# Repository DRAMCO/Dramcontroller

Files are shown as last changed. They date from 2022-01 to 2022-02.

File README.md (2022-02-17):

# Dramcontroller
HID controller board design for Engineering Experience 2.
The peripherals with corresponding pins are described below. 
A distinction is made between the on-board peripherals, I2C addresses and sensor slots

## On-board peripherals
| Peripherals | Corresponding GPIO Pin  |
|---|---|
| Buzzer | 2 |
| Vibrator 1 | 12 |
| Vibrator 2 | 5 |
| Debug LED | 13 |
| IO Expender INT | 11 |

## I2C addresses
Four IO expanders connected with the I2C bus control the 7 segment displays, led indicator array and GPIO 3 from every sensor slot. I2C sensors should use always other addresses to prevent collisions during operation.

| IO Expander | Corresponding I2C addres  |
|---|---|
| Sensor slot GPIO 3 | 0x38 |
| Segment display 2 | 0x39 |
| Segment display 1 | 0x3A |
| Led array | 0x3B |

## Sensor slots
### Sensor slot 1
| Peripheral | Pin | Comment |
|---|---|---|
| GPIO 1 | 6 | Digital |
| GPIO 2 | 14  | Digital - Analog |
| GPIO 3 | IO EXP pin 1 | Digital (0b00000001) |
| UART  |  | Serial |
| I2C  |  |  |

### Sensor slot 2
| Peripheral | Pin | Comment |
|---|---|---|
| GPIO 1 | 39 | Digital |
| GPIO 2 | 15  | Digital - Analog |
| GPIO 3 | IO EXP pin 2 | Digital (0b00000010) |
| UART  |  | Serial |
| I2C  |  |  |

### Sensor slot 3
| Peripheral | Pin | Comment |
|---|---|---|
| GPIO 1 | 8 | Digital |
| GPIO 2 | 16  | Digital - Analog |
| GPIO 3 | IO EXP pin 3 | Digital (0b00000100) |
| UART  |  | Serial |
| I2C  |  |  |

### Sensor slot 4
| Peripheral | Pin | Comment |
|---|---|---|
| GPIO 1 | 9 | Digital |
| GPIO 2 | 17  | Digital - Analog |
| GPIO 3 | IO EXP pin 4 | Digital (0b00001000) |
| UART  |  | Serial |
| I2C  |  |  |

### Sensor slot 5
| Peripheral | Pin | Comment |
|---|---|---|
| GPIO 1 | 10 | Digital |
| GPIO 2 | 18  | Digital - Analog |
| GPIO 3 | IO EXP pin 5 | Digital (0b00010000) |
| UART  |  | Serial1 |
| I2C  |  |  |

### Sensor slot 6
| Peripheral | Pin | Comment |
|---|---|---|
| GPIO 1 | 23 | Digital |
| GPIO 2 | 19  | Digital - Analog |
| GPIO 3 | IO EXP pin 6 | Digital (0b00100000) |
| UART  |  | Serial1 |
| I2C  |  |  |

### Sensor slot 7
| Peripheral | Pin | Comment |
|---|---|---|
| GPIO 1 | 24 | Digital |
| GPIO 2 | 4  | Digital - Analog |
| GPIO 3 | IO EXP pin 7 | Digital (0b01000000) |
| UART  |  | Serial1 |
| I2C  |  |  |

### Sensor slot 8
| Peripheral | Pin | Comment |
|---|---|---|
| GPIO 1 | 22 | Digital |
| GPIO 2 | 3  | Digital - Analog |
| GPIO 3 | IO EXP pin 8 | Digital (0b10000000) |
| UART  |  | Serial1 |
| I2C  |  |  |

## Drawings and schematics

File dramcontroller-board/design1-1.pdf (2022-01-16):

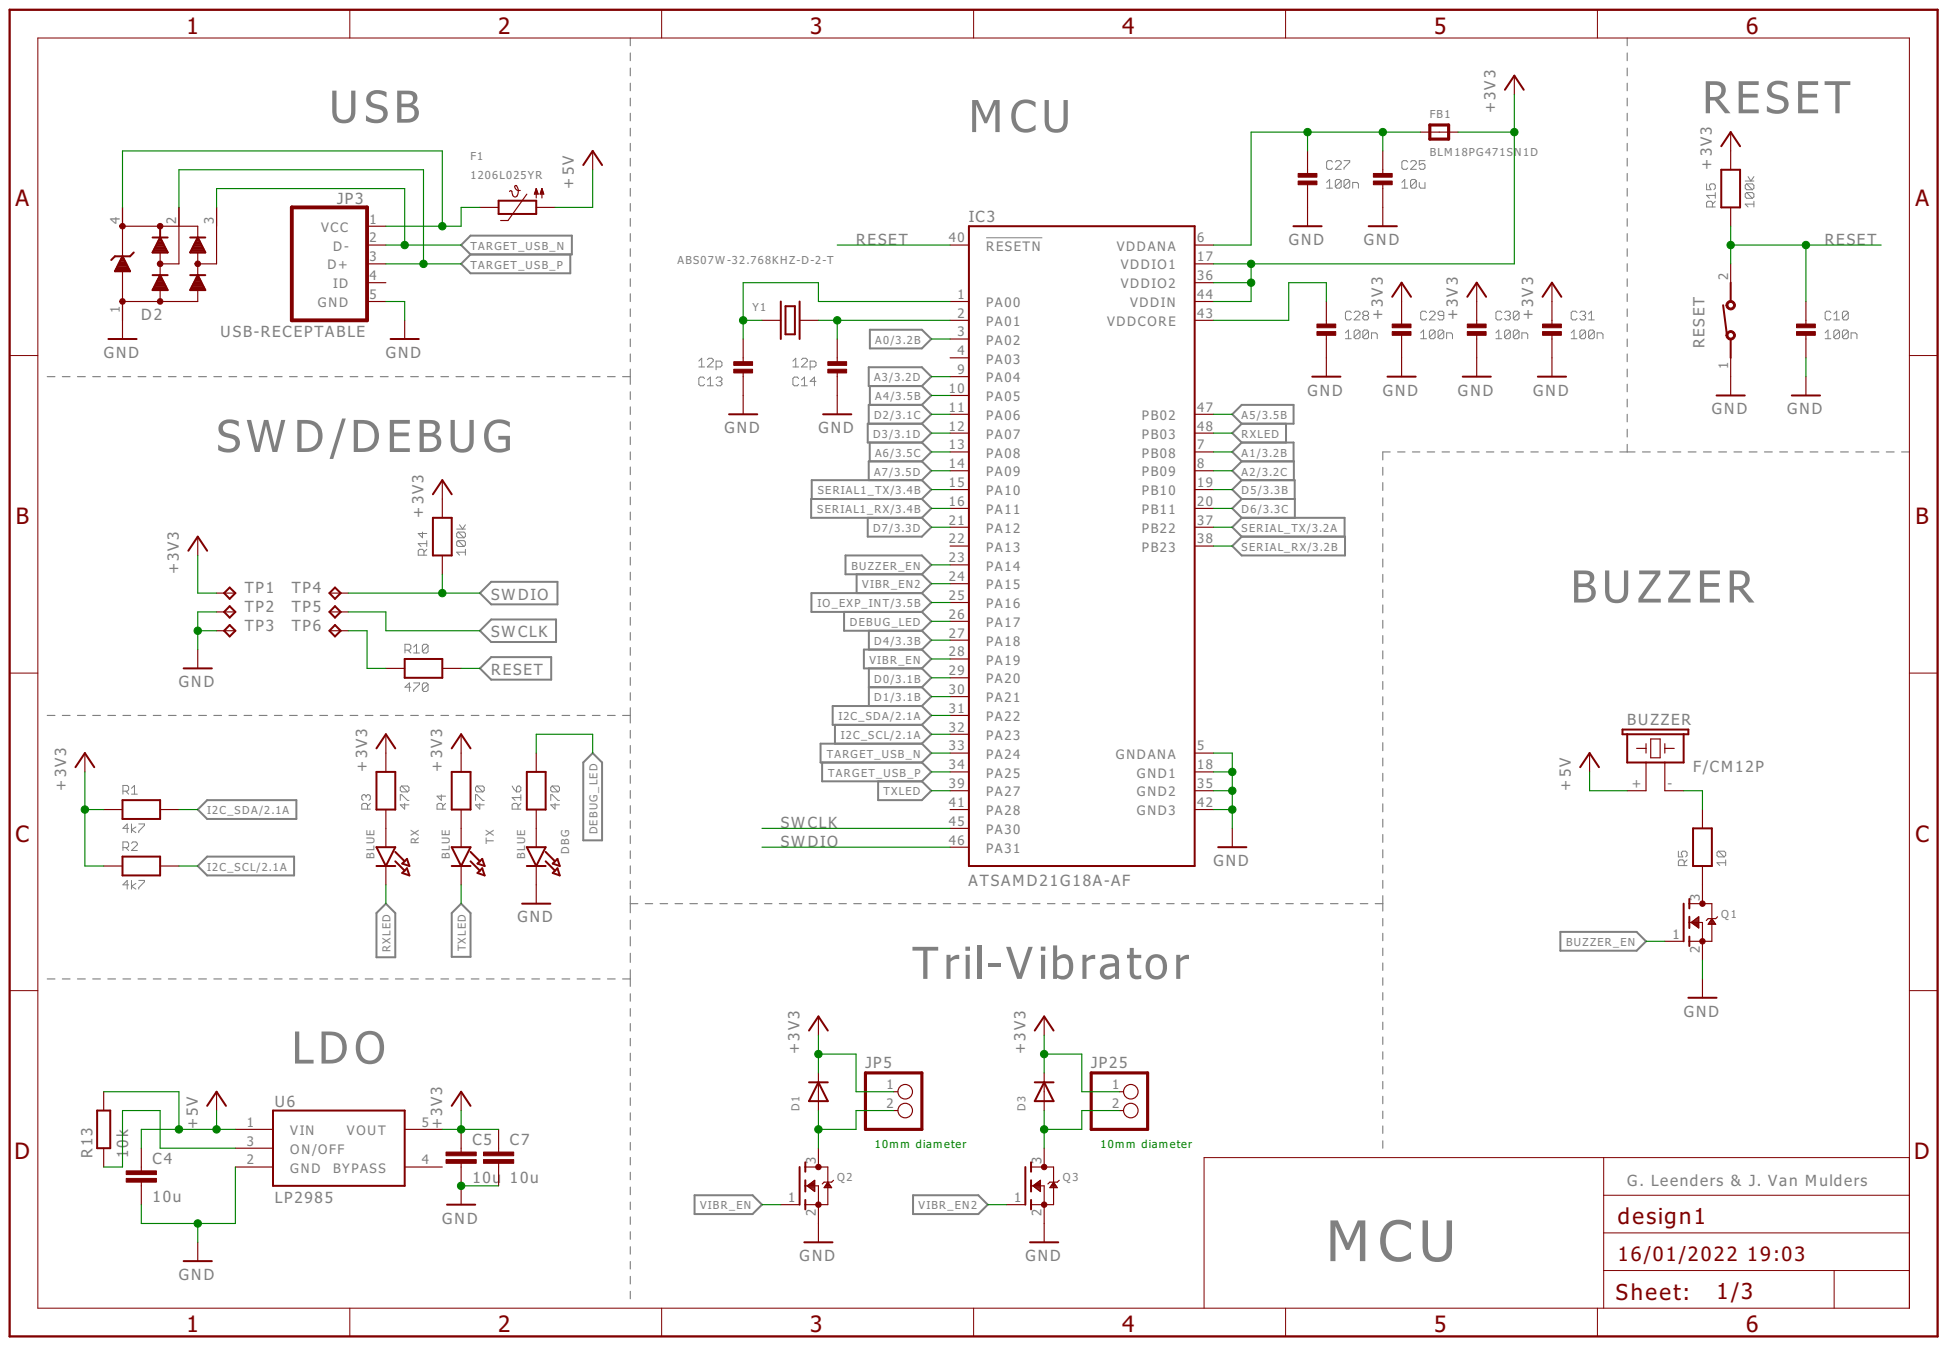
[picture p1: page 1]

G. Leenders & J. Van Mulders LDO

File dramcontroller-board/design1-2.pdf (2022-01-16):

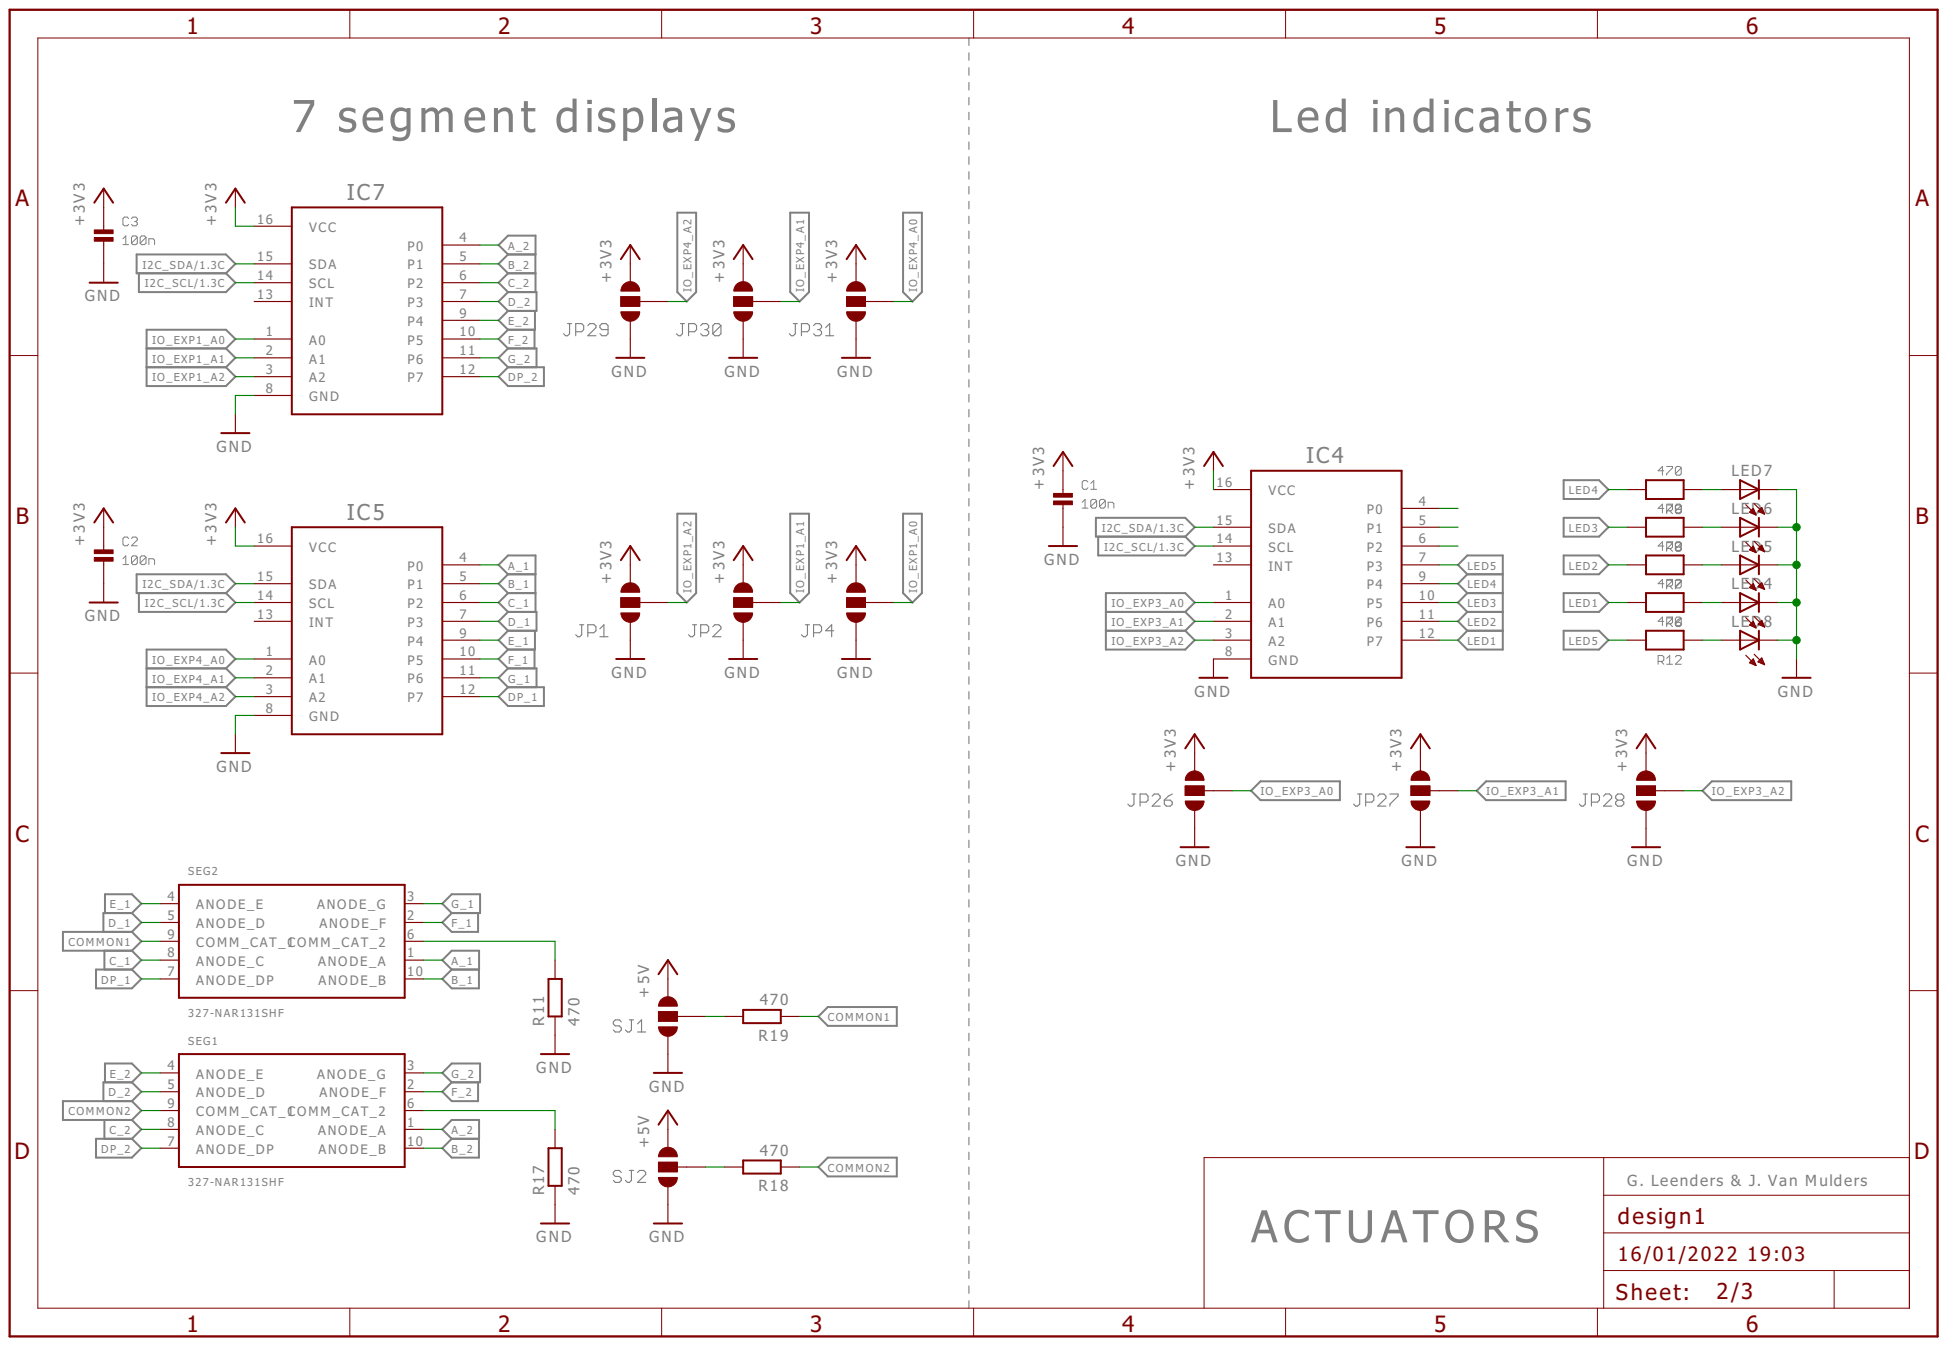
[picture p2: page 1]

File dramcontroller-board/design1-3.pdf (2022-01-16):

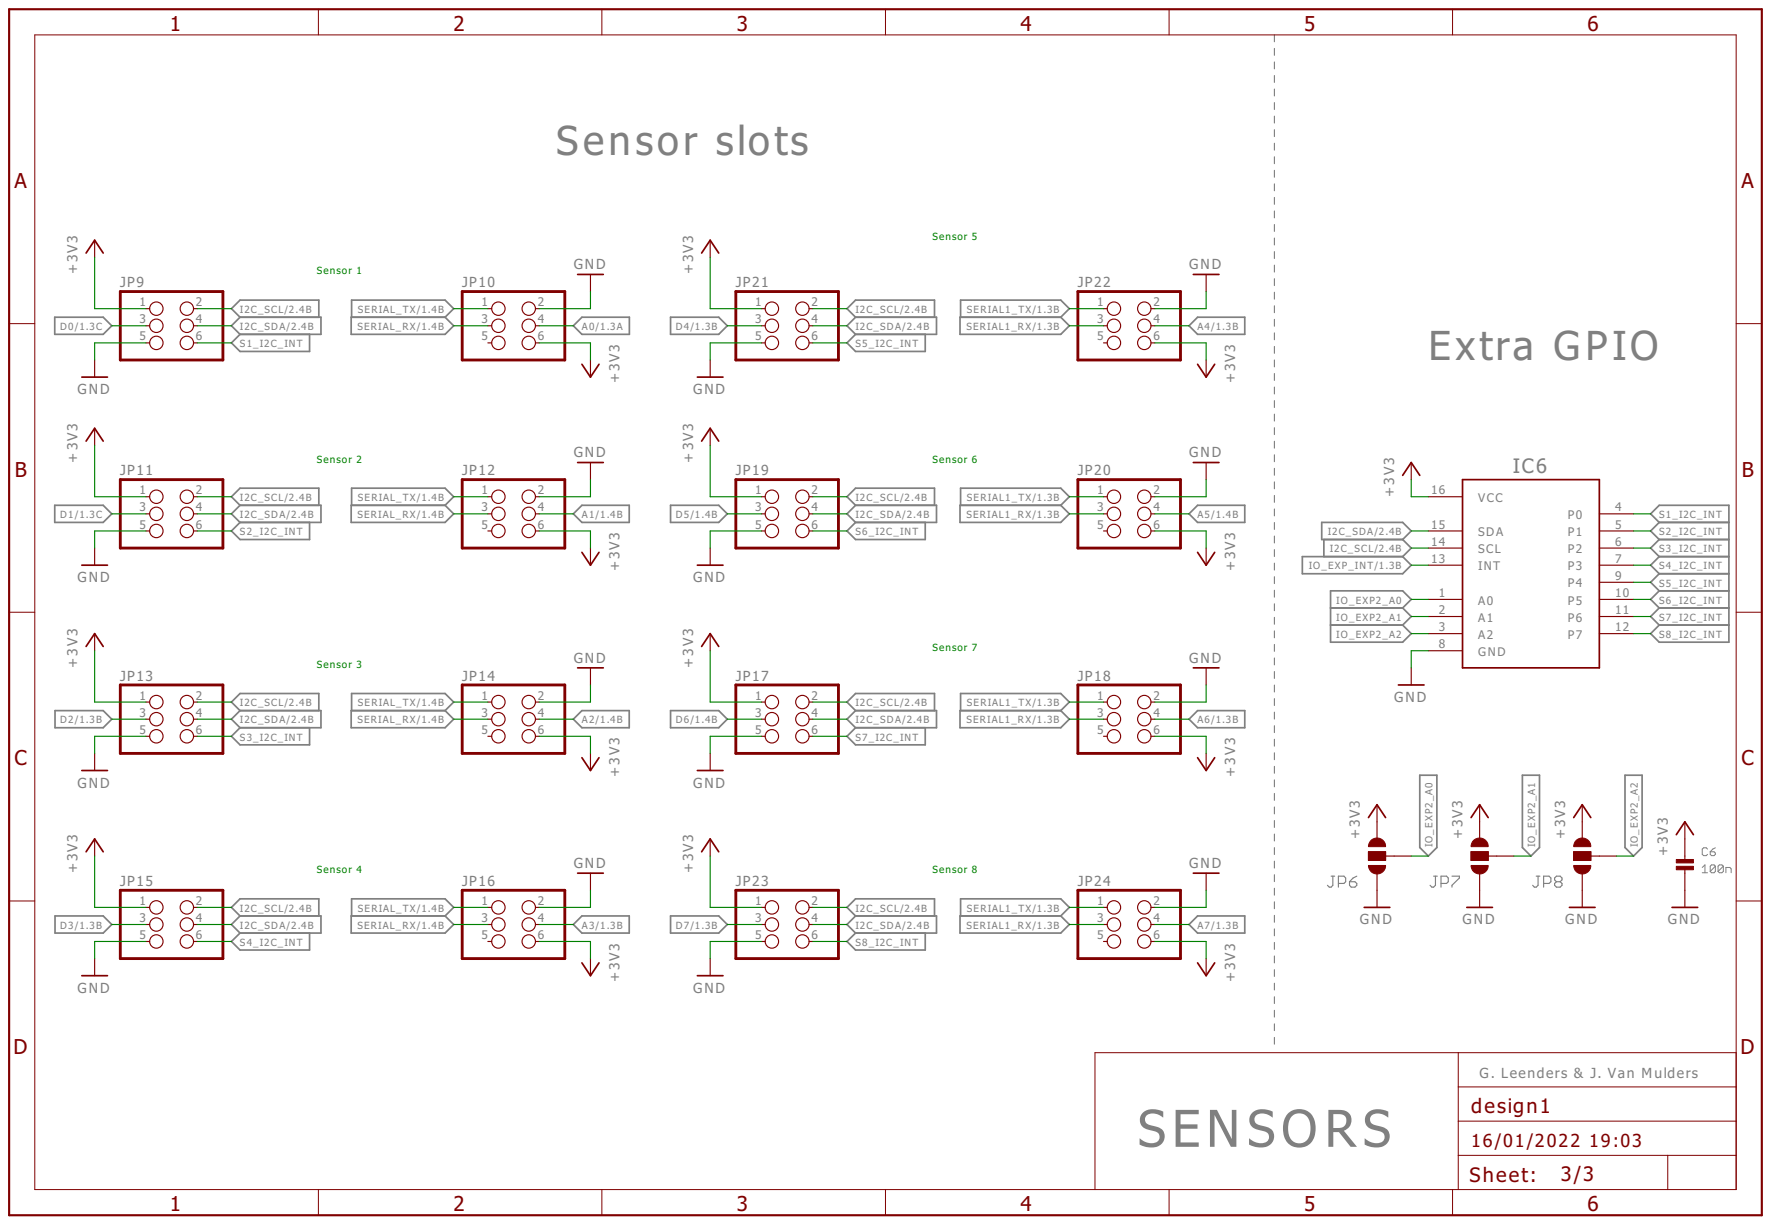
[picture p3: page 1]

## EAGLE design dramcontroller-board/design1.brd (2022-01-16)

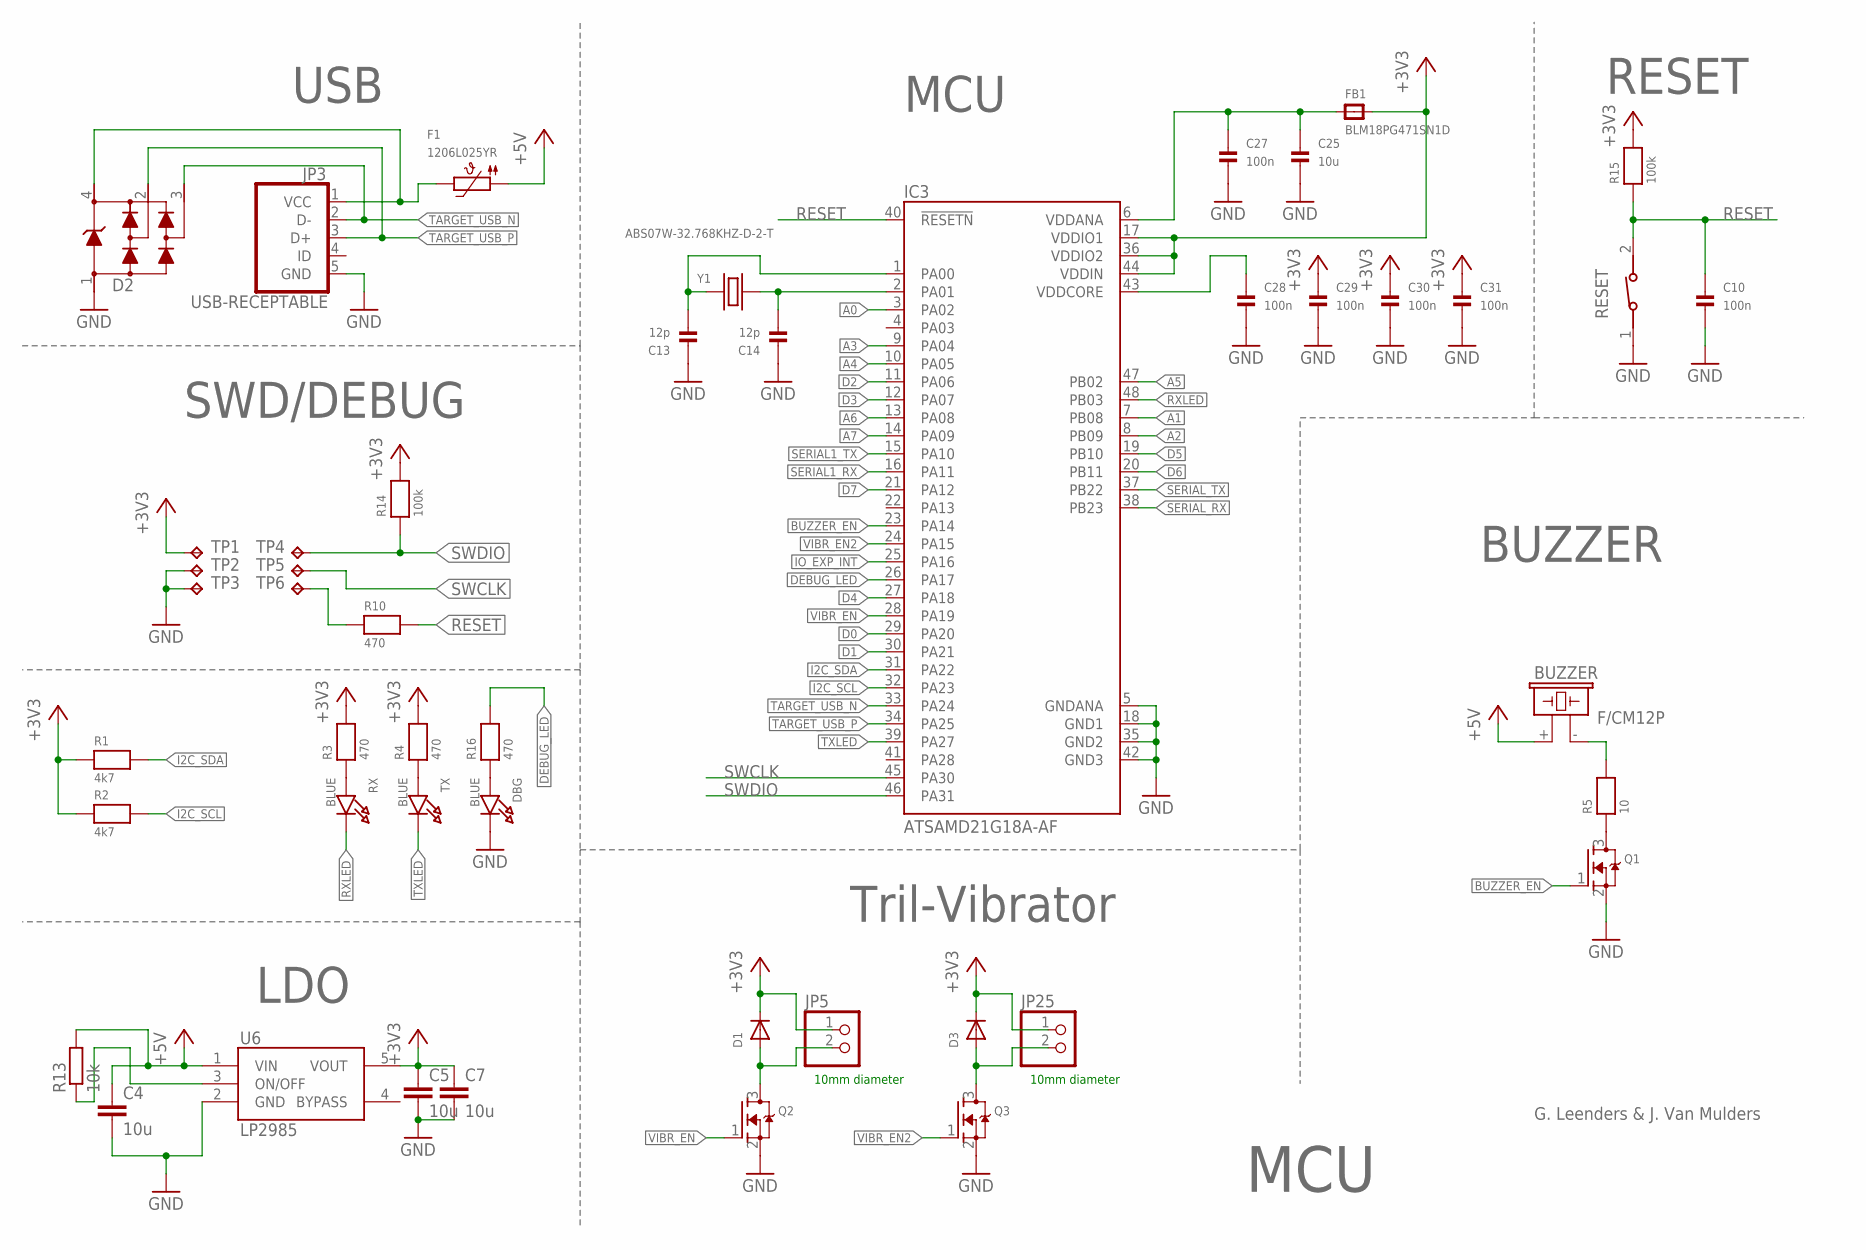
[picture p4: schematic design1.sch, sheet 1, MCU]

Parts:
BUZZER: F/CM12P
C4, C5, C7: 10u; C0805
C10, C27, C28, C29, C30, C31: 100n; 0603
C13, C14: 12p; 0603
C25: 10u; 0805
D1, D3: DIODESOD-123; SOD-123
D2: PRTR5V0U2X,215; SOT143B
DBG: BLUE; CHIPLED_0805
F1: 1206L025YR; 1206
FB1: BLM18PG471SN1D; _0603
IC3: ATSAMD21G18A-AF; QFP50P900X900X120-48N
JP3: USB-RECEPTABLE; FCI-10103594-0001LF
JP5, JP25: HEADER-1X2ROUND; 1X02_ROUND
Q1, Q2, Q3: MOSFET-NWIDE; SOT23-WIDE
R1, R2: 4k7; 0603
R3, R4, R10, R16: 470; 0603
R5: 10; 0603
R13: 10k; R0603
R14, R15: 100k; 0603
RESET: 434111043826
RX: BLUE; CHIPLED_0805
TP1, TP2, TP3, TP4, TP5, TP6: TPTP11R; TP11R
TX: BLUE; CHIPLED_0805
U6: LP2985AIM5-3.3; SOT25
Y1: ABS07W-32.768KHZ-D-2-T; XTAL320X150X90

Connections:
+3V3: C5.1, C7.1, C29.1, C30.1, C31.1, D1.C, D3.C, FB1.2, IC3.17 (VDDIO1), IC3.36 (VDDIO2), IC3.44 (VDDIN), JP5.1, JP25.1, R1.1, R2.1, R3.2, R4.2, R14.2, R15.2, TP1.TP, U6.5 (VOUT); also elsewhere on the board
+5V: BUZZER.+ (1), C4.1, F1.1, R13.2, U6.1 (VIN)
A0: IC3.3 (PA02); also elsewhere on the board
A1: IC3.7 (PB08); also elsewhere on the board
A2: IC3.8 (PB09); also elsewhere on the board
A3: IC3.9 (PA04); also elsewhere on the board
A4: IC3.10 (PA05); also elsewhere on the board
A5: IC3.47 (PB02); also elsewhere on the board
A6: IC3.13 (PA08); also elsewhere on the board
A7: IC3.14 (PA09); also elsewhere on the board
BUZZER_EN: IC3.23 (PA14), Q1.1 (G)
D0: IC3.29 (PA20); also elsewhere on the board
D1: IC3.30 (PA21); also elsewhere on the board
D2: IC3.11 (PA06); also elsewhere on the board
D3: IC3.12 (PA07); also elsewhere on the board
D4: IC3.27 (PA18); also elsewhere on the board
D5: IC3.19 (PB10); also elsewhere on the board
D6: IC3.20 (PB11); also elsewhere on the board
D7: IC3.21 (PA12); also elsewhere on the board
DEBUG_LED: IC3.26 (PA17), R16.2
GND: C4.2, C5.2, C7.2, C10.2, C13.1, C14.1, C25.2, C27.2, C28.2, C29.2, C30.2, C31.2, D2.1, DBG.C, IC3.5 (GNDANA), IC3.18 (GND1), IC3.35 (GND2), IC3.42 (GND3), JP3.5 (GND), Q1.2 (S), Q2.2 (S), Q3.2 (S), RESET.1, TP2.TP, TP3.TP, U6.2 (GND); also elsewhere on the board
I2C_SCL: IC3.32 (PA23), R2.2; also elsewhere on the board
I2C_SDA: IC3.31 (PA22), R1.2; also elsewhere on the board
IO_EXP_INT: IC3.25 (PA16); also elsewhere on the board
LDO_EN: R13.1, U6.3 (ON/OFF)
unnamed: R3.1, RX.A
unnamed: R4.1, TX.A
unnamed: BUZZER.- (2), R5.2
unnamed: C28.1, IC3.43 (VDDCORE)
unnamed: Q1.3 (D), R5.1
unnamed: C25.1, C27.1, FB1.1, IC3.6 (VDDANA)
unnamed: D2.4, F1.2, JP3.1 (VCC)
unnamed: D3.A, JP25.2, Q3.3 (D)
unnamed: C13.2, IC3.1 (PA00), Y1.1
unnamed: C14.2, IC3.2 (PA01), Y1.2
unnamed: DBG.A, R16.1
unnamed: R10.1, TP6.TP
unnamed: D1.A, JP5.2, Q2.3 (D)
RESET: C10.1, IC3.40 (!RESETN), R10.2, R15.1, RESET.2
RXLED: IC3.48 (PB03), RX.C
SERIAL1_RX: IC3.16 (PA11); also elsewhere on the board
SERIAL1_TX: IC3.15 (PA10); also elsewhere on the board
SERIAL_RX: IC3.38 (PB23); also elsewhere on the board
SERIAL_TX: IC3.37 (PB22); also elsewhere on the board
SWCLK: IC3.45 (PA30), TP5.TP
SWDIO: IC3.46 (PA31), R14.1, TP4.TP
TARGET_USB_N: D2.3, IC3.33 (PA24), JP3.2 (D-)
TARGET_USB_P: D2.2, IC3.34 (PA25), JP3.3 (D+)
TXLED: IC3.39 (PA27), TX.C
VIBR_EN: IC3.28 (PA19), Q2.1 (G)
VIBR_EN2: IC3.24 (PA15), Q3.1 (G)

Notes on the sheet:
10mm diameter
MCU
G. Leenders & J. Van Mulders
LDO
USB
SWD/DEBUG
RESET
BUZZER
Tril-Vibrator

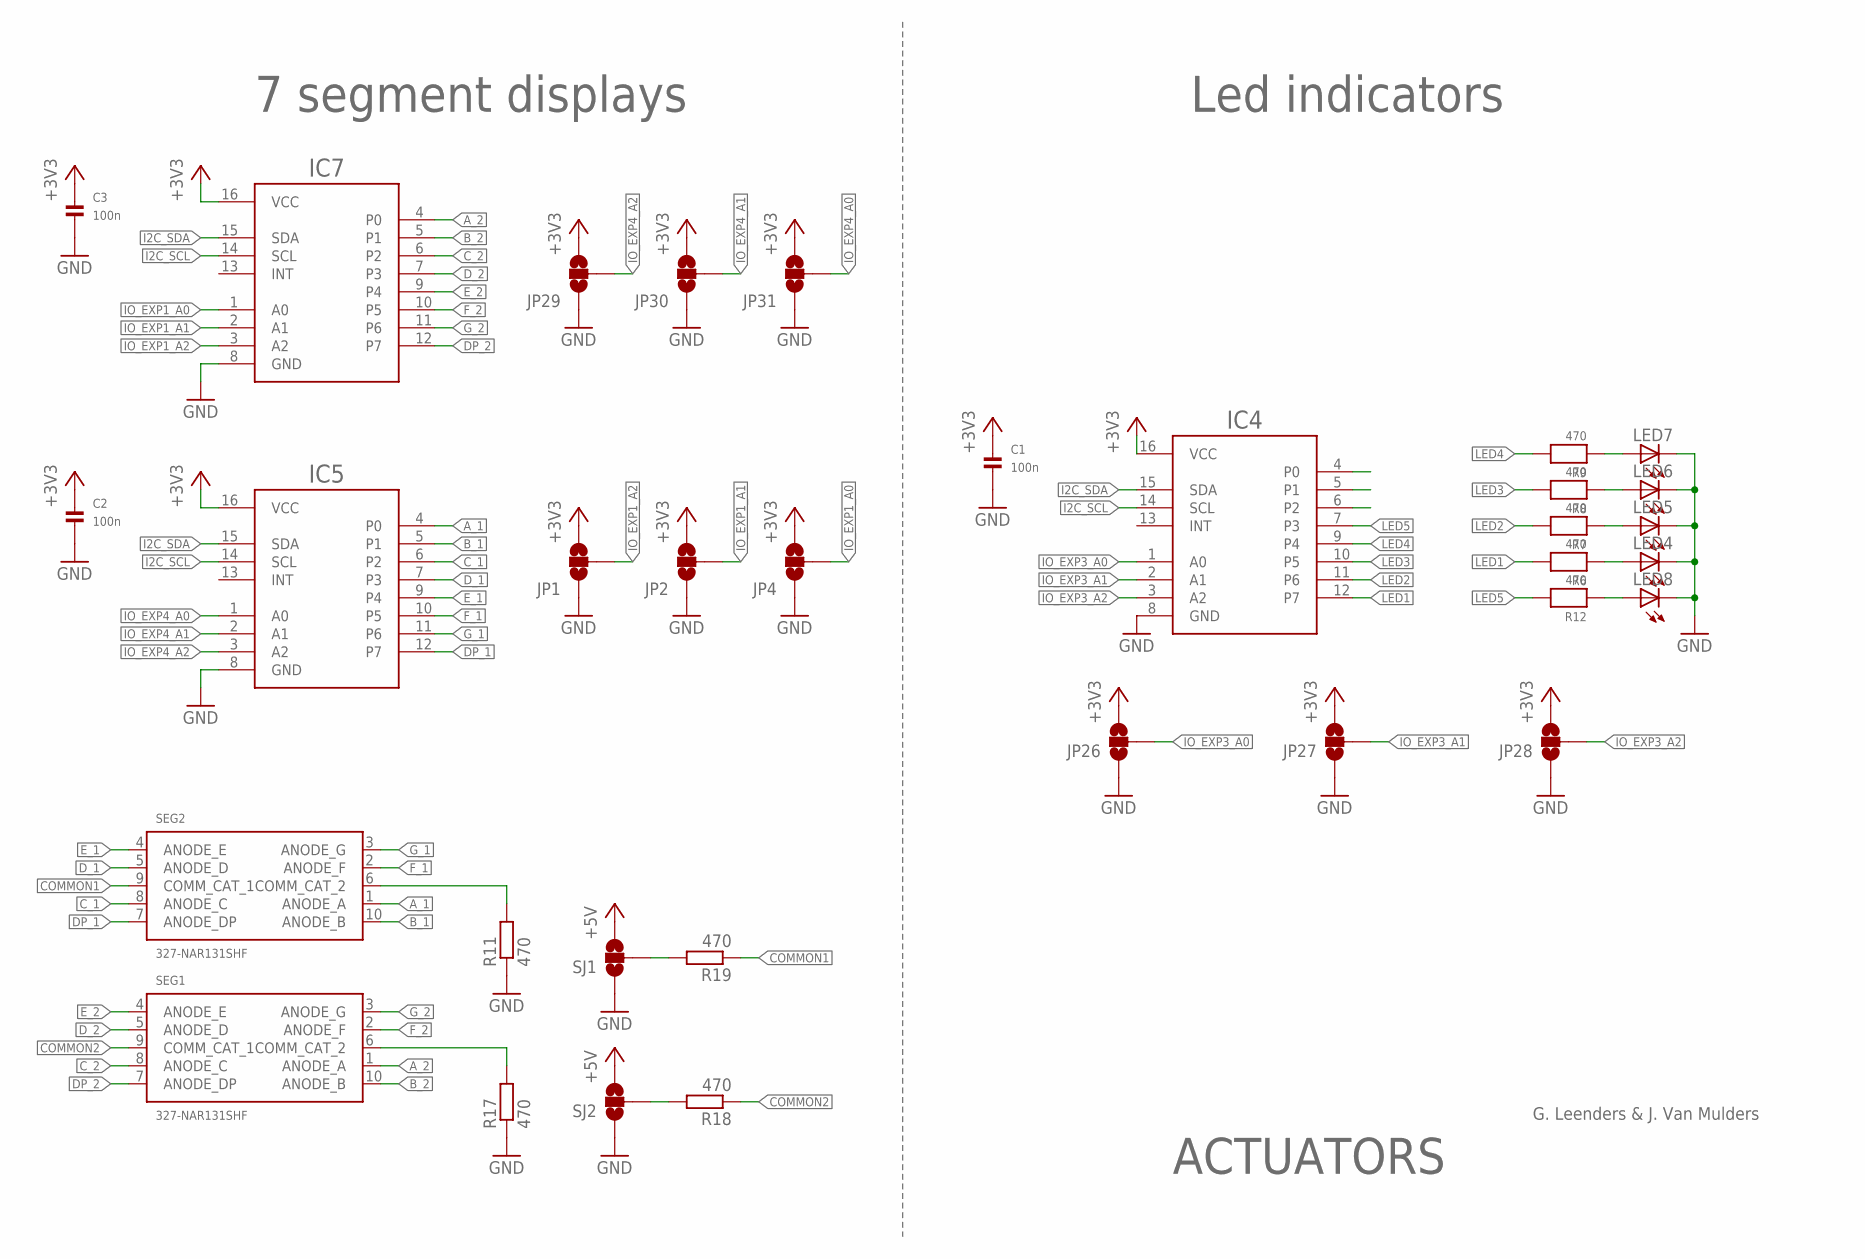
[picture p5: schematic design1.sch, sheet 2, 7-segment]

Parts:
C1, C2, C3: 100n; 0603
IC4, IC5, IC7: TCA9554ADBR; SSOP-16
JP1, JP2, JP4, JP26, JP27, JP28, JP29, JP30, JP31: JUMPER-SMT_3_NO_NO-SILK; SMT-JUMPER_3_NO_NO-SILK
LED4, LED5, LED6, LED7, LED8: LED3MM
R6, R7, R8, R9, R12: 470; 0603
R11, R17, R18, R19: 470; R0603
SEG1, SEG2: 327-NAR131SHF; NAR131SH-F
SJ1, SJ2: JUMPER-SMT_3_NO_NO-SILK; SMT-JUMPER_3_NO_NO-SILK

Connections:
+3V3: C1.1, C2.1, C3.1, IC4.16 (VCC), IC5.16 (VCC), IC7.16 (VCC), JP1.3, JP2.3, JP4.3, JP26.3, JP27.3, JP28.3, JP29.3, JP30.3, JP31.3, SJ1.3, SJ2.3; also elsewhere on the board
A_1: IC5.4 (P0), SEG2.1 (ANODE_A)
A_2: IC7.4 (P0), SEG1.1 (ANODE_A)
B_1: IC5.5 (P1), SEG2.10 (ANODE_B)
B_2: IC7.5 (P1), SEG1.10 (ANODE_B)
COMMON1: R19.1, SEG2.9 (COMM_CAT_1)
COMMON2: R18.1, SEG1.9 (COMM_CAT_1)
C_1: IC5.6 (P2), SEG2.8 (ANODE_C)
C_2: IC7.6 (P2), SEG1.8 (ANODE_C)
DP_1: IC5.12 (P7), SEG2.7 (ANODE_DP)
DP_2: IC7.12 (P7), SEG1.7 (ANODE_DP)
D_1: IC5.7 (P3), SEG2.5 (ANODE_D)
D_2: IC7.7 (P3), SEG1.5 (ANODE_D)
E_1: IC5.9 (P4), SEG2.4 (ANODE_E)
E_2: IC7.9 (P4), SEG1.4 (ANODE_E)
F_1: IC5.10 (P5), SEG2.2 (ANODE_F)
F_2: IC7.10 (P5), SEG1.2 (ANODE_F)
GND: C1.2, C2.2, C3.2, IC4.8 (GND), IC5.8 (GND), IC7.8 (GND), JP1.1, JP2.1, JP4.1, JP26.1, JP27.1, JP28.1, JP29.1, JP30.1, JP31.1, LED4.K (C), LED5.K (C), LED6.K (C), LED7.K (C), LED8.K (C), R11.1, R17.1, SJ1.1, SJ2.1; also elsewhere on the board
G_1: IC5.11 (P6), SEG2.3 (ANODE_G)
G_2: IC7.11 (P6), SEG1.3 (ANODE_G)
I2C_SCL: IC4.14 (SCL), IC5.14 (SCL), IC7.14 (SCL); also elsewhere on the board
I2C_SDA: IC4.15 (SDA), IC5.15 (SDA), IC7.15 (SDA); also elsewhere on the board
IO_EXP1_A0: IC7.1 (A0), JP4.2
IO_EXP1_A1: IC7.2 (A1), JP2.2
IO_EXP1_A2: IC7.3 (A2), JP1.2
IO_EXP3_A0: IC4.1 (A0), JP26.2
IO_EXP3_A1: IC4.2 (A1), JP27.2
IO_EXP3_A2: IC4.3 (A2), JP28.2
IO_EXP4_A0: IC5.1 (A0), JP31.2
IO_EXP4_A1: IC5.2 (A1), JP30.2
IO_EXP4_A2: IC5.3 (A2), JP29.2
LED1: IC4.12 (P7), R6.2
LED2: IC4.11 (P6), R7.2
LED3: IC4.10 (P5), R8.2
LED4: IC4.9 (P4), R9.2
LED5: IC4.7 (P3), R12.2
unnamed: R17.2, SEG1.6 (COMM_CAT_2)
unnamed: LED8.A, R12.1
unnamed: LED4.A, R6.1
unnamed: LED5.A, R7.1
unnamed: LED6.A, R8.1
unnamed: LED7.A, R9.1
unnamed: R11.2, SEG2.6 (COMM_CAT_2)
unnamed: R19.2, SJ1.2
unnamed: R18.2, SJ2.2

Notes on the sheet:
ACTUATORS
7 segment displays
Led indicators
G. Leenders & J. Van Mulders

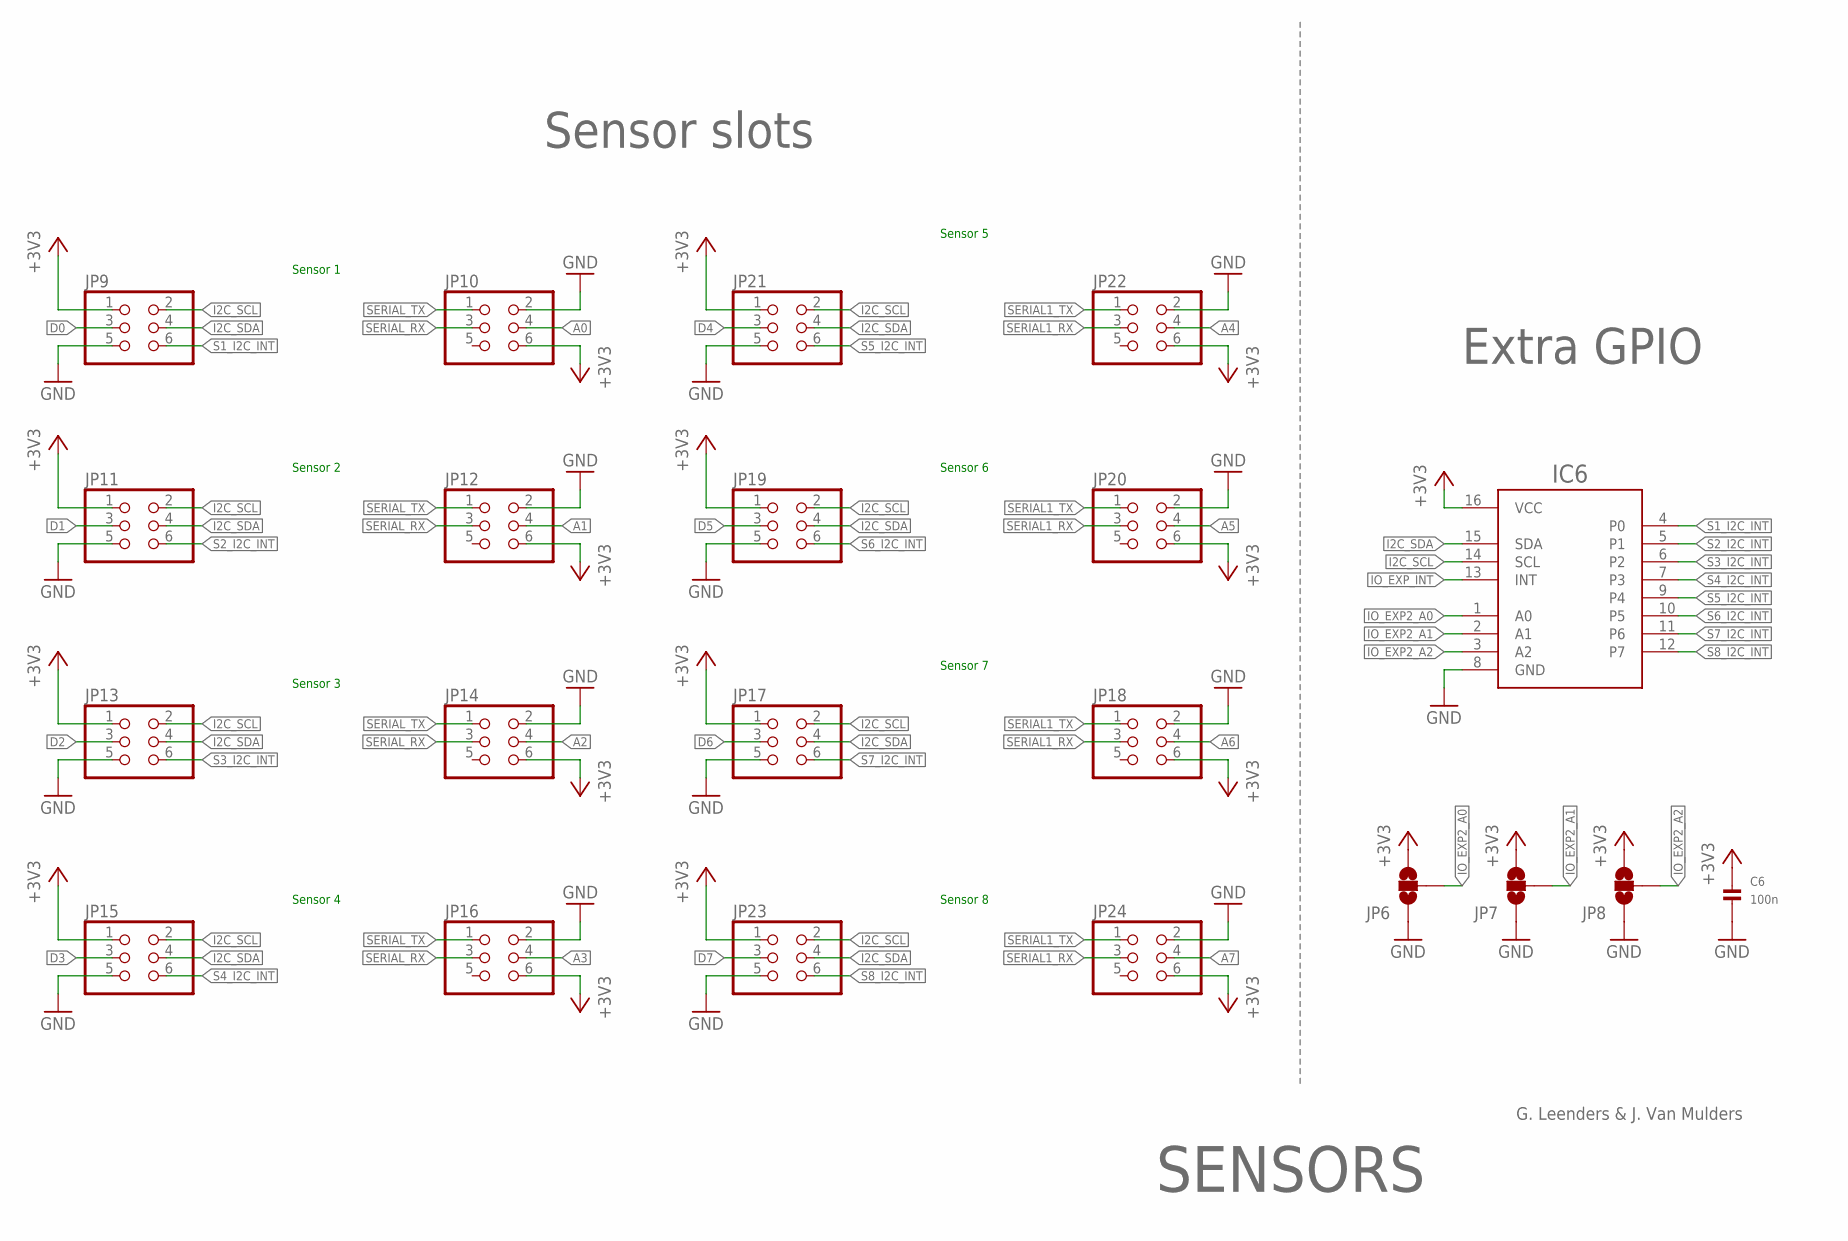
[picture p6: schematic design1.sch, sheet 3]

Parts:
C6: 100n; 0603
IC6: TCA9554ADBR; SSOP-16
JP6, JP7, JP8: JUMPER-SMT_3_NO_NO-SILK; SMT-JUMPER_3_NO_NO-SILK
JP9, JP10, JP11, JP12, JP13, JP14, JP15, JP16, JP17, JP18, JP19, JP20, JP21, JP22, JP23, JP24: HEADER-2X3; 2X03_ROUND_70MIL

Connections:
+3V3: C6.1, IC6.16 (VCC), JP6.3, JP7.3, JP8.3, JP9.1, JP10.6, JP11.1, JP12.6, JP13.1, JP14.6, JP15.1, JP16.6, JP17.1, JP18.6, JP19.1, JP20.6, JP21.1, JP22.6, JP23.1, JP24.6; also elsewhere on the board
A0: JP10.4; also elsewhere on the board
A1: JP12.4; also elsewhere on the board
A2: JP14.4; also elsewhere on the board
A3: JP16.4; also elsewhere on the board
A4: JP22.4; also elsewhere on the board
A5: JP20.4; also elsewhere on the board
A6: JP18.4; also elsewhere on the board
A7: JP24.4; also elsewhere on the board
D0: JP9.3; also elsewhere on the board
D1: JP11.3; also elsewhere on the board
D2: JP13.3; also elsewhere on the board
D3: JP15.3; also elsewhere on the board
D4: JP21.3; also elsewhere on the board
D5: JP19.3; also elsewhere on the board
D6: JP17.3; also elsewhere on the board
D7: JP23.3; also elsewhere on the board
GND: C6.2, IC6.8 (GND), JP6.1, JP7.1, JP8.1, JP9.5, JP10.2, JP11.5, JP12.2, JP13.5, JP14.2, JP15.5, JP16.2, JP17.5, JP18.2, JP19.5, JP20.2, JP21.5, JP22.2, JP23.5, JP24.2; also elsewhere on the board
I2C_SCL: IC6.14 (SCL), JP9.2, JP11.2, JP13.2, JP15.2, JP17.2, JP19.2, JP21.2, JP23.2; also elsewhere on the board
I2C_SDA: IC6.15 (SDA), JP9.4, JP11.4, JP13.4, JP15.4, JP17.4, JP19.4, JP21.4, JP23.4; also elsewhere on the board
IO_EXP2_A0: IC6.1 (A0), JP6.2
IO_EXP2_A1: IC6.2 (A1), JP7.2
IO_EXP2_A2: IC6.3 (A2), JP8.2
IO_EXP_INT: IC6.13 (INT); also elsewhere on the board
S1_I2C_INT: IC6.4 (P0), JP9.6
S2_I2C_INT: IC6.5 (P1), JP11.6
S3_I2C_INT: IC6.6 (P2), JP13.6
S4_I2C_INT: IC6.7 (P3), JP15.6
S5_I2C_INT: IC6.9 (P4), JP21.6
S6_I2C_INT: IC6.10 (P5), JP19.6
S7_I2C_INT: IC6.11 (P6), JP17.6
S8_I2C_INT: IC6.12 (P7), JP23.6
SERIAL1_RX: JP18.3, JP20.3, JP22.3, JP24.3; also elsewhere on the board
SERIAL1_TX: JP18.1, JP20.1, JP22.1, JP24.1; also elsewhere on the board
SERIAL_RX: JP10.3, JP12.3, JP14.3, JP16.3; also elsewhere on the board
SERIAL_TX: JP10.1, JP12.1, JP14.1, JP16.1; also elsewhere on the board

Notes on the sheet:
Sensor 5
Sensor 6
Sensor 7
Sensor 8
Sensor 1
Sensor 2
Sensor 3
Sensor 4
SENSORS
G. Leenders & J. Van Mulders
Sensor slots
Extra GPIO

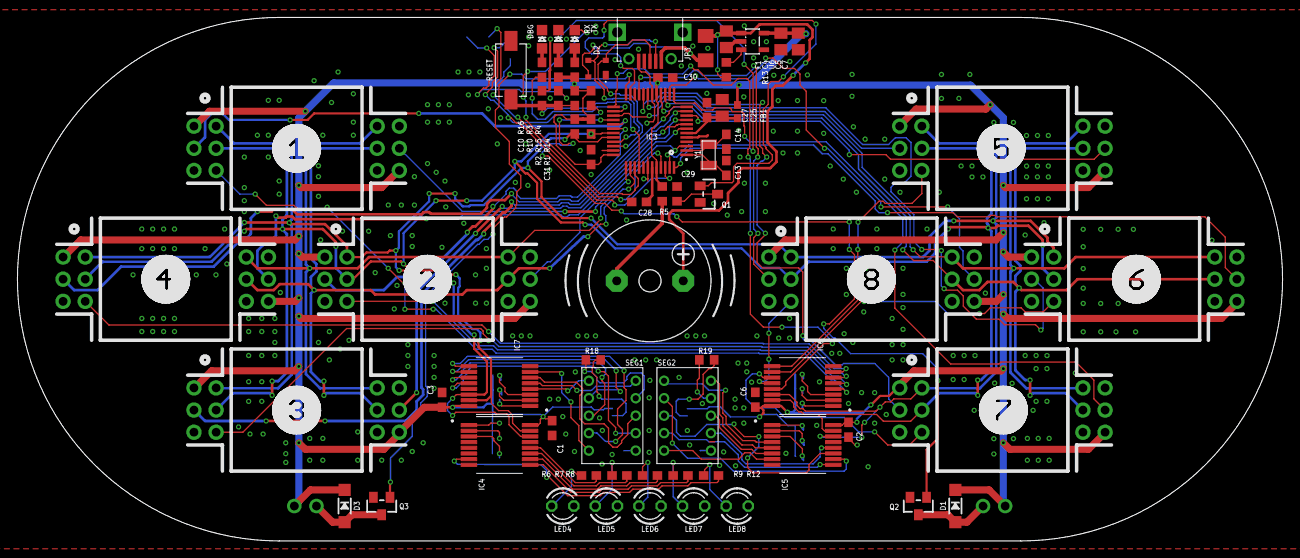
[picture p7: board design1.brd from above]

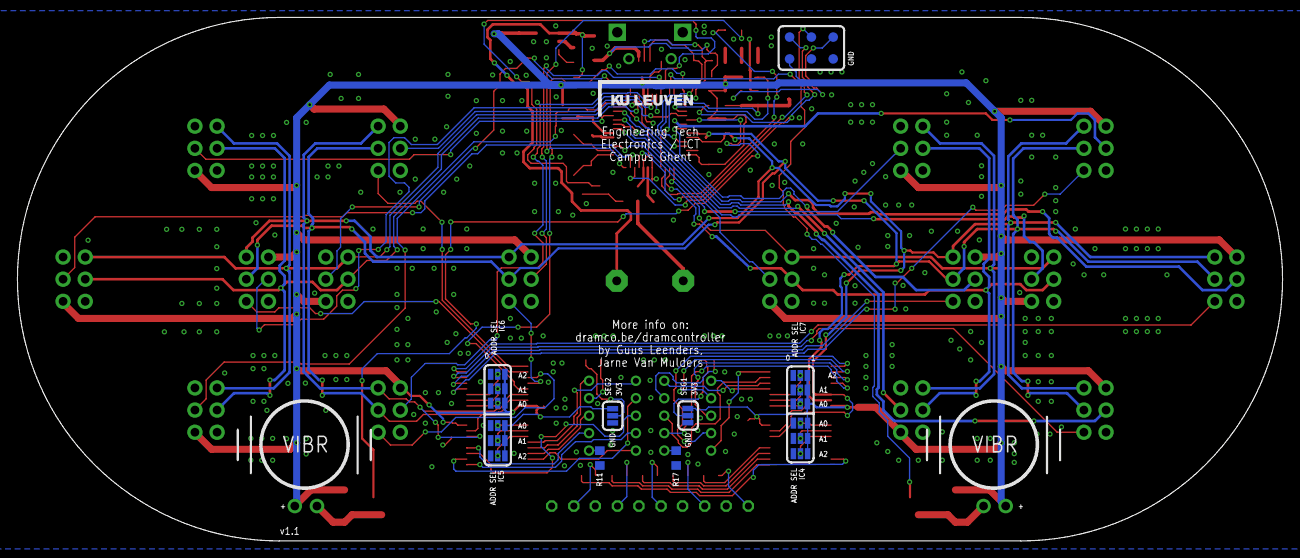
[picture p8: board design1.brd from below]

Board: 2 copper layers, 145.0 x 60.0 mm, 101 parts (40 on the bottom side), 103 nets.

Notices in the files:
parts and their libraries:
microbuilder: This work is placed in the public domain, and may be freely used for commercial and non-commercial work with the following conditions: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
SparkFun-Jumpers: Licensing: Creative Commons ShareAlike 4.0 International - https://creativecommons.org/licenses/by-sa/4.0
